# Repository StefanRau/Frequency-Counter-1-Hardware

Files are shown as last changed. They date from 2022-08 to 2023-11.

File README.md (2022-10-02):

# Frequency-Counter-1-hardware
This repository contains CAD data of Frequency Counter 1

Project repositories are:
- [Project](https://github.com/StefanRau/Frequency-Counter-1-Project)
- [Hardware](https://github.com/StefanRau/Frequency-Counter-1-Hardware)
- [Software](https://github.com/StefanRau/Frequency-Counter-1-Arduino)
- [PC terminal software](https://github.com/StefanRau/Frequency-Counter-1-Terminal)
## Main Board
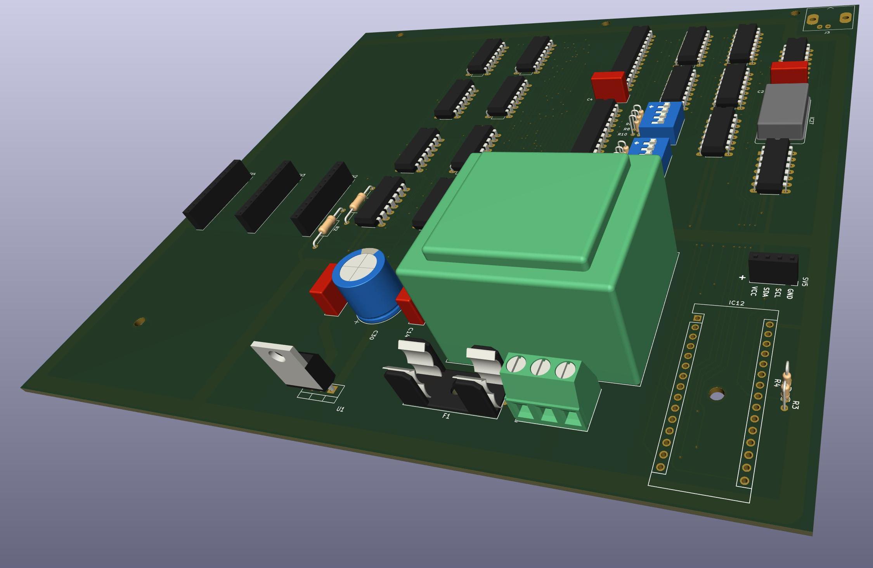
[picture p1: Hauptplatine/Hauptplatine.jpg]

## Front Plate
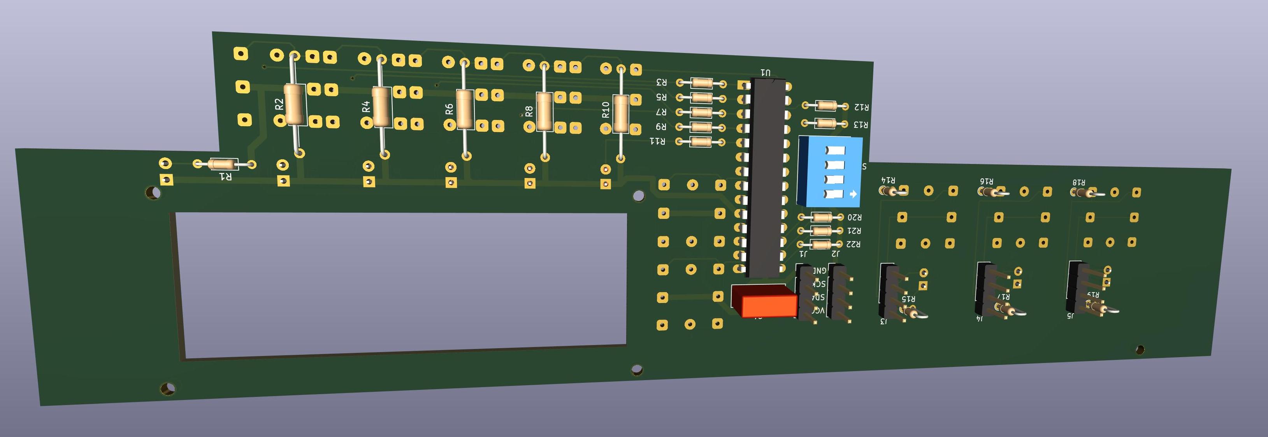
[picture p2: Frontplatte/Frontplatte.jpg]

## 100 MHz TTL CMOS
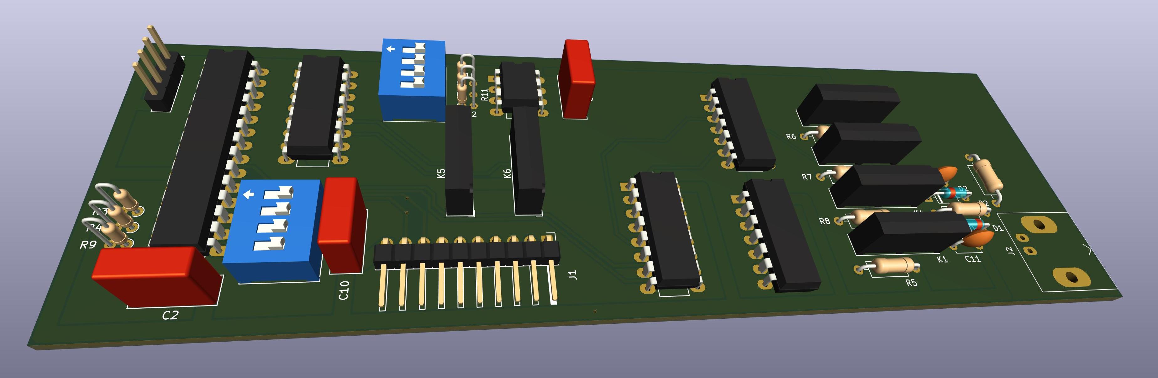
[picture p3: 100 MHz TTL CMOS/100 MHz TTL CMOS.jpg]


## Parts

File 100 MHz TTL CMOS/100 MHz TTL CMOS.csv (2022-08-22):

Source: | C:\Stefan\Backup\Projekte\Frequency Counter\V1.0\SchaltungKiCad\100 MHz TTL CMOS\100 MHz TTL CMOS.kicad_sch
Date: | 16.08.2022 20:28:54
Tool: | Eeschema (6.0.5)
Generator: | C:\Program Files\KiCad\6.0\bin\scripting\plugins/bom_csv_grouped_by_value_with_fp.py
Component Count: | 36
Ref | Qnty | Value | Cmp name | Footprint | Description | Vendor
C2, C4, C10, | 3 | 100nF | C-Device-100-MHz-TTL-CMOS-rescue | Capacitor_THT:C_Rect_L10.0mm_W4.0mm_P7.50mm_FKS3_FKP3
C11, C12, | 2 | 10pF | C-Device-100-MHz-TTL-CMOS-rescue | Capacitor_THT:C_Disc_D4.7mm_W2.5mm_P5.00mm
D1, D2, | 2 | BAT43 | BAT43-Diode-100-MHz-TTL-CMOS-rescue | Diode_THT:D_DO-35_SOD27_P7.62mm_Horizontal
IC1, | 1 | 74LS14 | 74HC14-74xx-100-MHz-TTL-CMOS-rescue | Package_DIP:DIP-14_W7.62mm_LongPads
IC2, | 1 | MCP23017_SO | MCP23017_SO-Interface_Expansion-100-MHz-TTL-CMOS-rescue | Package_DIP:DIP-28_W7.62mm_LongPads
IC3, | 1 | 74HC14 | 74HC14-74xx-100-MHz-TTL-CMOS-rescue | Package_DIP:DIP-14_W7.62mm_LongPads
IC4, | 1 | 24LC256 | 24LC256 | Package_DIP:DIP-8_W7.62mm_LongPads | I2C Serial EEPROM, 256Kb, DIP-8/SOIC-8/TSSOP-8/DFN-8
IC5, | 1 | 74HC151 | 74LS151-74xx-100-MHz-TTL-CMOS-rescue | Package_DIP:DIP-16_W7.62mm_LongPads
IC6, | 1 | ULN2003 | ULN2003-Transistor_Array-100-MHz-TTL-CMOS-rescue | Package_DIP:DIP-16_W7.62mm_LongPads
J1, | 1 | Conn_01x10_Male | Conn_01x10_Male-Connector-100-MHz-TTL-CMOS-rescue | Connector_PinHeader_2.54mm:PinHeader_1x10_P2.54mm_Horizontal
J2, | 1 | Conn_Coaxial | Conn_Coaxial-Connector-100-MHz-TTL-CMOS-rescue | Connector_Coaxial:BNC_Amphenol_B6252HB-NPP3G-50_Horizontal
J3, | 1 | Conn_01x04_Male | Conn_01x04_Male-Connector-100-MHz-TTL-CMOS-rescue | Connector_PinHeader_2.54mm:PinHeader_1x04_P2.54mm_Vertical
K1, K2, K3, K4, K5, K6, | 6 | UMS05-1A80-75D | UMS05-1A80-75D | Relay_THT:Relay_SPST_StandexMeder_MS_Form1AB | Standex Meder UMS reed relay, SPST, Closing Contact, with diode
R1, | 1 | 1M | R-Device-100-MHz-TTL-CMOS-rescue | Resistor_THT:R_Axial_DIN0207_L6.3mm_D2.5mm_P10.16mm_Horizontal
R2, | 1 | 330 | R-Device-100-MHz-TTL-CMOS-rescue | Resistor_THT:R_Axial_DIN0207_L6.3mm_D2.5mm_P10.16mm_Horizontal
R3, R4, R9, R10, R11, R12, | 6 | 4,7k | R-Device-100-MHz-TTL-CMOS-rescue | Resistor_THT:R_Axial_DIN0204_L3.6mm_D1.6mm_P1.90mm_Vertical
R5, R7, R8, | 3 | 4,7k | R-Device-100-MHz-TTL-CMOS-rescue | Resistor_THT:R_Axial_DIN0207_L6.3mm_D2.5mm_P10.16mm_Horizontal
R6, | 1 | 10k | R-Device-100-MHz-TTL-CMOS-rescue | Resistor_THT:R_Axial_DIN0207_L6.3mm_D2.5mm_P10.16mm_Horizontal
SW1, SW2, | 2 | SW_DIP_x04 | SW_DIP_x04-Switch-100-MHz-TTL-CMOS-rescue | Button_Switch_THT:SW_DIP_SPSTx04_Slide_9.78x12.34mm_W7.62mm_P2.54mm

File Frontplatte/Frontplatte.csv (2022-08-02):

Source: | C:\Users\d028312\OneDrive - SAP SE\Projekte\Frequency Counter\SchaltungKiCad\Frontplatte\Frontplatte.kicad_sch
Date: | 07.03.2022 16:20:37
Tool: | Eeschema (6.0.2)
Generator: | C:\Program Files\KiCad\6.0\bin\scripting\plugins/bom_csv_grouped_by_value.py
Component Count: | 49
Individual Components:
Item | Qty | Reference(s) | Value | LibPart | Footprint | Datasheet
 |  | C1 | 100nF | Frontplatte-rescue:C-Device-Frontplatte-rescue | Capacitor_THT:C_Rect_L10.0mm_W4.0mm_P7.50mm_FKS3_FKP3
 |  | D1 | LED | Frontplatte-rescue:LED-Device-Frontplatte-rescue | LED_THT:LED_D5.0mm
 |  | D2 | LED | Frontplatte-rescue:LED-Device-Frontplatte-rescue | LED_THT:LED_D5.0mm
 |  | D3 | LED | Frontplatte-rescue:LED-Device-Frontplatte-rescue | LED_THT:LED_D5.0mm
 |  | D4 | LED | Frontplatte-rescue:LED-Device-Frontplatte-rescue | LED_THT:LED_D5.0mm
 |  | D5 | LED | Frontplatte-rescue:LED-Device-Frontplatte-rescue | LED_THT:LED_D5.0mm
 |  | D6 | LED | Frontplatte-rescue:LED-Device-Frontplatte-rescue | LED_THT:LED_D5.0mm
 |  | D7 | LED | Frontplatte-rescue:LED-Device-Frontplatte-rescue | LED_THT:LED_D5.0mm
 |  | D8 | LED | Frontplatte-rescue:LED-Device-Frontplatte-rescue | LED_THT:LED_D5.0mm
 |  | D9 | LED | Frontplatte-rescue:LED-Device-Frontplatte-rescue | LED_THT:LED_D5.0mm
 |  | J1 | Conn_01x04_Male | Frontplatte-rescue:Conn_01x04_Male-Connector-Frontplatte-rescue | Connector_PinHeader_2.54mm:PinHeader_1x04_P2.54mm_Vertical
 |  | J2 | Conn_01x04_Male | Frontplatte-rescue:Conn_01x04_Male-Connector-Frontplatte-rescue | Connector_PinHeader_2.54mm:PinHeader_1x04_P2.54mm_Vertical
 |  | J3 | Conn_01x04_Male | Frontplatte-rescue:Conn_01x04_Male-Connector-Frontplatte-rescue | Connector_PinHeader_2.54mm:PinHeader_1x04_P2.54mm_Vertical
 |  | J4 | Conn_01x04_Male | Frontplatte-rescue:Conn_01x04_Male-Connector-Frontplatte-rescue | Connector_PinHeader_2.54mm:PinHeader_1x04_P2.54mm_Vertical
 |  | J5 | Conn_01x04_Male | Frontplatte-rescue:Conn_01x04_Male-Connector-Frontplatte-rescue | Connector_PinHeader_2.54mm:PinHeader_1x04_P2.54mm_Vertical
 |  | R1 | 220 | Frontplatte-rescue:R-Device-Frontplatte-rescue | Resistor_THT:R_Axial_DIN0204_L3.6mm_D1.6mm_P7.62mm_Horizontal
 |  | R2 | 4,7k | Frontplatte-rescue:R-Device-Frontplatte-rescue | Resistor_THT:R_Axial_DIN0207_L6.3mm_D2.5mm_P15.24mm_Horizontal
 |  | R3 | 220 | Frontplatte-rescue:R-Device-Frontplatte-rescue | Resistor_THT:R_Axial_DIN0204_L3.6mm_D1.6mm_P7.62mm_Horizontal
 |  | R4 | 4,7k | Frontplatte-rescue:R-Device-Frontplatte-rescue | Resistor_THT:R_Axial_DIN0207_L6.3mm_D2.5mm_P15.24mm_Horizontal
 |  | R5 | 220 | Frontplatte-rescue:R-Device-Frontplatte-rescue | Resistor_THT:R_Axial_DIN0204_L3.6mm_D1.6mm_P7.62mm_Horizontal
 |  | R6 | 4,7k | Frontplatte-rescue:R-Device-Frontplatte-rescue | Resistor_THT:R_Axial_DIN0207_L6.3mm_D2.5mm_P15.24mm_Horizontal
 |  | R7 | 220 | Frontplatte-rescue:R-Device-Frontplatte-rescue | Resistor_THT:R_Axial_DIN0204_L3.6mm_D1.6mm_P7.62mm_Horizontal
 |  | R8 | 4,7k | Frontplatte-rescue:R-Device-Frontplatte-rescue | Resistor_THT:R_Axial_DIN0207_L6.3mm_D2.5mm_P15.24mm_Horizontal
 |  | R9 | 220 | Frontplatte-rescue:R-Device-Frontplatte-rescue | Resistor_THT:R_Axial_DIN0204_L3.6mm_D1.6mm_P7.62mm_Horizontal
 |  | R10 | 4,7k | Frontplatte-rescue:R-Device-Frontplatte-rescue | Resistor_THT:R_Axial_DIN0207_L6.3mm_D2.5mm_P15.24mm_Horizontal
 |  | R11 | 220 | Frontplatte-rescue:R-Device-Frontplatte-rescue | Resistor_THT:R_Axial_DIN0204_L3.6mm_D1.6mm_P7.62mm_Horizontal
 |  | R12 | 4,7k | Frontplatte-rescue:R-Device-Frontplatte-rescue | Resistor_THT:R_Axial_DIN0204_L3.6mm_D1.6mm_P7.62mm_Horizontal
 |  | R13 | 4,7k | Frontplatte-rescue:R-Device-Frontplatte-rescue | Resistor_THT:R_Axial_DIN0204_L3.6mm_D1.6mm_P7.62mm_Horizontal
 |  | R14 | 4,7k | Frontplatte-rescue:R-Device-Frontplatte-rescue | Resistor_THT:R_Axial_DIN0204_L3.6mm_D1.6mm_P1.90mm_Vertical
 |  | R15 | 220 | Frontplatte-rescue:R-Device-Frontplatte-rescue | Resistor_THT:R_Axial_DIN0204_L3.6mm_D1.6mm_P1.90mm_Vertical
 |  | R16 | 4,7k | Frontplatte-rescue:R-Device-Frontplatte-rescue | Resistor_THT:R_Axial_DIN0204_L3.6mm_D1.6mm_P1.90mm_Vertical
 |  | R17 | 220 | Frontplatte-rescue:R-Device-Frontplatte-rescue | Resistor_THT:R_Axial_DIN0204_L3.6mm_D1.6mm_P1.90mm_Vertical
 |  | R18 | 4,7k | Frontplatte-rescue:R-Device-Frontplatte-rescue | Resistor_THT:R_Axial_DIN0204_L3.6mm_D1.6mm_P1.90mm_Vertical
 |  | R19 | 220 | Frontplatte-rescue:R-Device-Frontplatte-rescue | Resistor_THT:R_Axial_DIN0204_L3.6mm_D1.6mm_P1.90mm_Vertical
 |  | R20 | 4,7k | Frontplatte-rescue:R-Device-Frontplatte-rescue | Resistor_THT:R_Axial_DIN0204_L3.6mm_D1.6mm_P7.62mm_Horizontal
 |  | R21 | 4,7k | Frontplatte-rescue:R-Device-Frontplatte-rescue | Resistor_THT:R_Axial_DIN0204_L3.6mm_D1.6mm_P7.62mm_Horizontal
 |  | R22 | 4,7k | Frontplatte-rescue:R-Device-Frontplatte-rescue | Resistor_THT:R_Axial_DIN0204_L3.6mm_D1.6mm_P7.62mm_Horizontal
 |  | S1 | SCHADOW_Button | Frontplatte-rescue:SCHADOW_Button-Frequenzzähler-Frontplatte-rescue | Libs:SCHADOW_Button
 |  | S2 | SCHADOW_Button | Frontplatte-rescue:SCHADOW_Button-Frequenzzähler-Frontplatte-rescue | Libs:SCHADOW_Button
 |  | S3 | SCHADOW_Button | Frontplatte-rescue:SCHADOW_Button-Frequenzzähler-Frontplatte-rescue | Libs:SCHADOW_Button
 |  | S4 | SCHADOW_Button | Frontplatte-rescue:SCHADOW_Button-Frequenzzähler-Frontplatte-rescue | Libs:SCHADOW_Button
 |  | S5 | SCHADOW_Button | Frontplatte-rescue:SCHADOW_Button-Frequenzzähler-Frontplatte-rescue | Libs:SCHADOW_Button
 |  | S6 | SCHADOW_Button | Frontplatte-rescue:SCHADOW_Button-Frequenzzähler-Frontplatte-rescue | Libs:SCHADOW_Button
 |  | S7 | SCHADOW_Button | Frontplatte-rescue:SCHADOW_Button-Frequenzzähler-Frontplatte-rescue | Libs:SCHADOW_Button
 |  | S8 | SCHADOW_Button | Frontplatte-rescue:SCHADOW_Button-Frequenzzähler-Frontplatte-rescue | Libs:SCHADOW_Button
 |  | S9 | SCHADOW_Button | Frontplatte-rescue:SCHADOW_Button-Frequenzzähler-Frontplatte-rescue | Libs:SCHADOW_Button
 |  | S10 | SCHADOW_Button | Frontplatte-rescue:SCHADOW_Button-Frequenzzähler-Frontplatte-rescue | Libs:SCHADOW_Button
 |  | SW1 | SW_DIP_x04 | Frontplatte-rescue:SW_DIP_x04-Switch-Frontplatte-rescue | Button_Switch_THT:SW_DIP_SPSTx04_Slide_9.78x12.34mm_W7.62mm_P2.54mm
 |  | U1 | MCP23017_SP | Frontplatte-rescue:MCP23017_SP-Interface_Expansion-Frontplatte-rescue | Package_DIP:DIP-28_W7.62mm | http://ww1.microchip.com/downloads/en/DeviceDoc/20001952C.pdf
Collated Components:
Item | Qty | Reference(s) | Value | LibPart | Footprint | Datasheet
1 | 1 | C1 | 100nF | Frontplatte-rescue:C-Device-Frontplatte-rescue | Capacitor_THT:C_Rect_L10.0mm_W4.0mm_P7.50mm_FKS3_FKP3
2 | 9 | D1, D2, D3, D4, D5, D6, D7, D8, D9 | LED | Frontplatte-rescue:LED-Device-Frontplatte-rescue | LED_THT:LED_D5.0mm
3 | 5 | J1, J2, J3, J4, J5 | Conn_01x04_Male | Frontplatte-rescue:Conn_01x04_Male-Connector-Frontplatte-rescue | Connector_PinHeader_2.54mm:PinHeader_1x04_P2.54mm_Vertical
4 | 6 | R1, R3, R5, R7, R9, R11 | 220 | Frontplatte-rescue:R-Device-Frontplatte-rescue | Resistor_THT:R_Axial_DIN0204_L3.6mm_D1.6mm_P7.62mm_Horizontal
5 | 5 | R2, R4, R6, R8, R10 | 4,7k | Frontplatte-rescue:R-Device-Frontplatte-rescue | Resistor_THT:R_Axial_DIN0207_L6.3mm_D2.5mm_P15.24mm_Horizontal
6 | 5 | R12, R13, R20, R21, R22 | 4,7k | Frontplatte-rescue:R-Device-Frontplatte-rescue | Resistor_THT:R_Axial_DIN0204_L3.6mm_D1.6mm_P7.62mm_Horizontal
7 | 3 | R14, R16, R18 | 4,7k | Frontplatte-rescue:R-Device-Frontplatte-rescue | Resistor_THT:R_Axial_DIN0204_L3.6mm_D1.6mm_P1.90mm_Vertical
8 | 3 | R15, R17, R19 | 220 | Frontplatte-rescue:R-Device-Frontplatte-rescue | Resistor_THT:R_Axial_DIN0204_L3.6mm_D1.6mm_P1.90mm_Vertical
9 | 10 | S1, S2, S3, S4, S5, S6, S7, S8, S9, S10 | SCHADOW_Button | Frontplatte-rescue:SCHADOW_Button-Frequenzzähler-Frontplatte-rescue | Libs:SCHADOW_Button
10 | 1 | SW1 | SW_DIP_x04 | Frontplatte-rescue:SW_DIP_x04-Switch-Frontplatte-rescue | Button_Switch_THT:SW_DIP_SPSTx04_Slide_9.78x12.34mm_W7.62mm_P2.54mm
11 | 1 | U1 | MCP23017_SP | Frontplatte-rescue:MCP23017_SP-Interface_Expansion-Frontplatte-rescue | Package_DIP:DIP-28_W7.62mm | http://ww1.microchip.com/downloads/en/DeviceDoc/20001952C.pdf

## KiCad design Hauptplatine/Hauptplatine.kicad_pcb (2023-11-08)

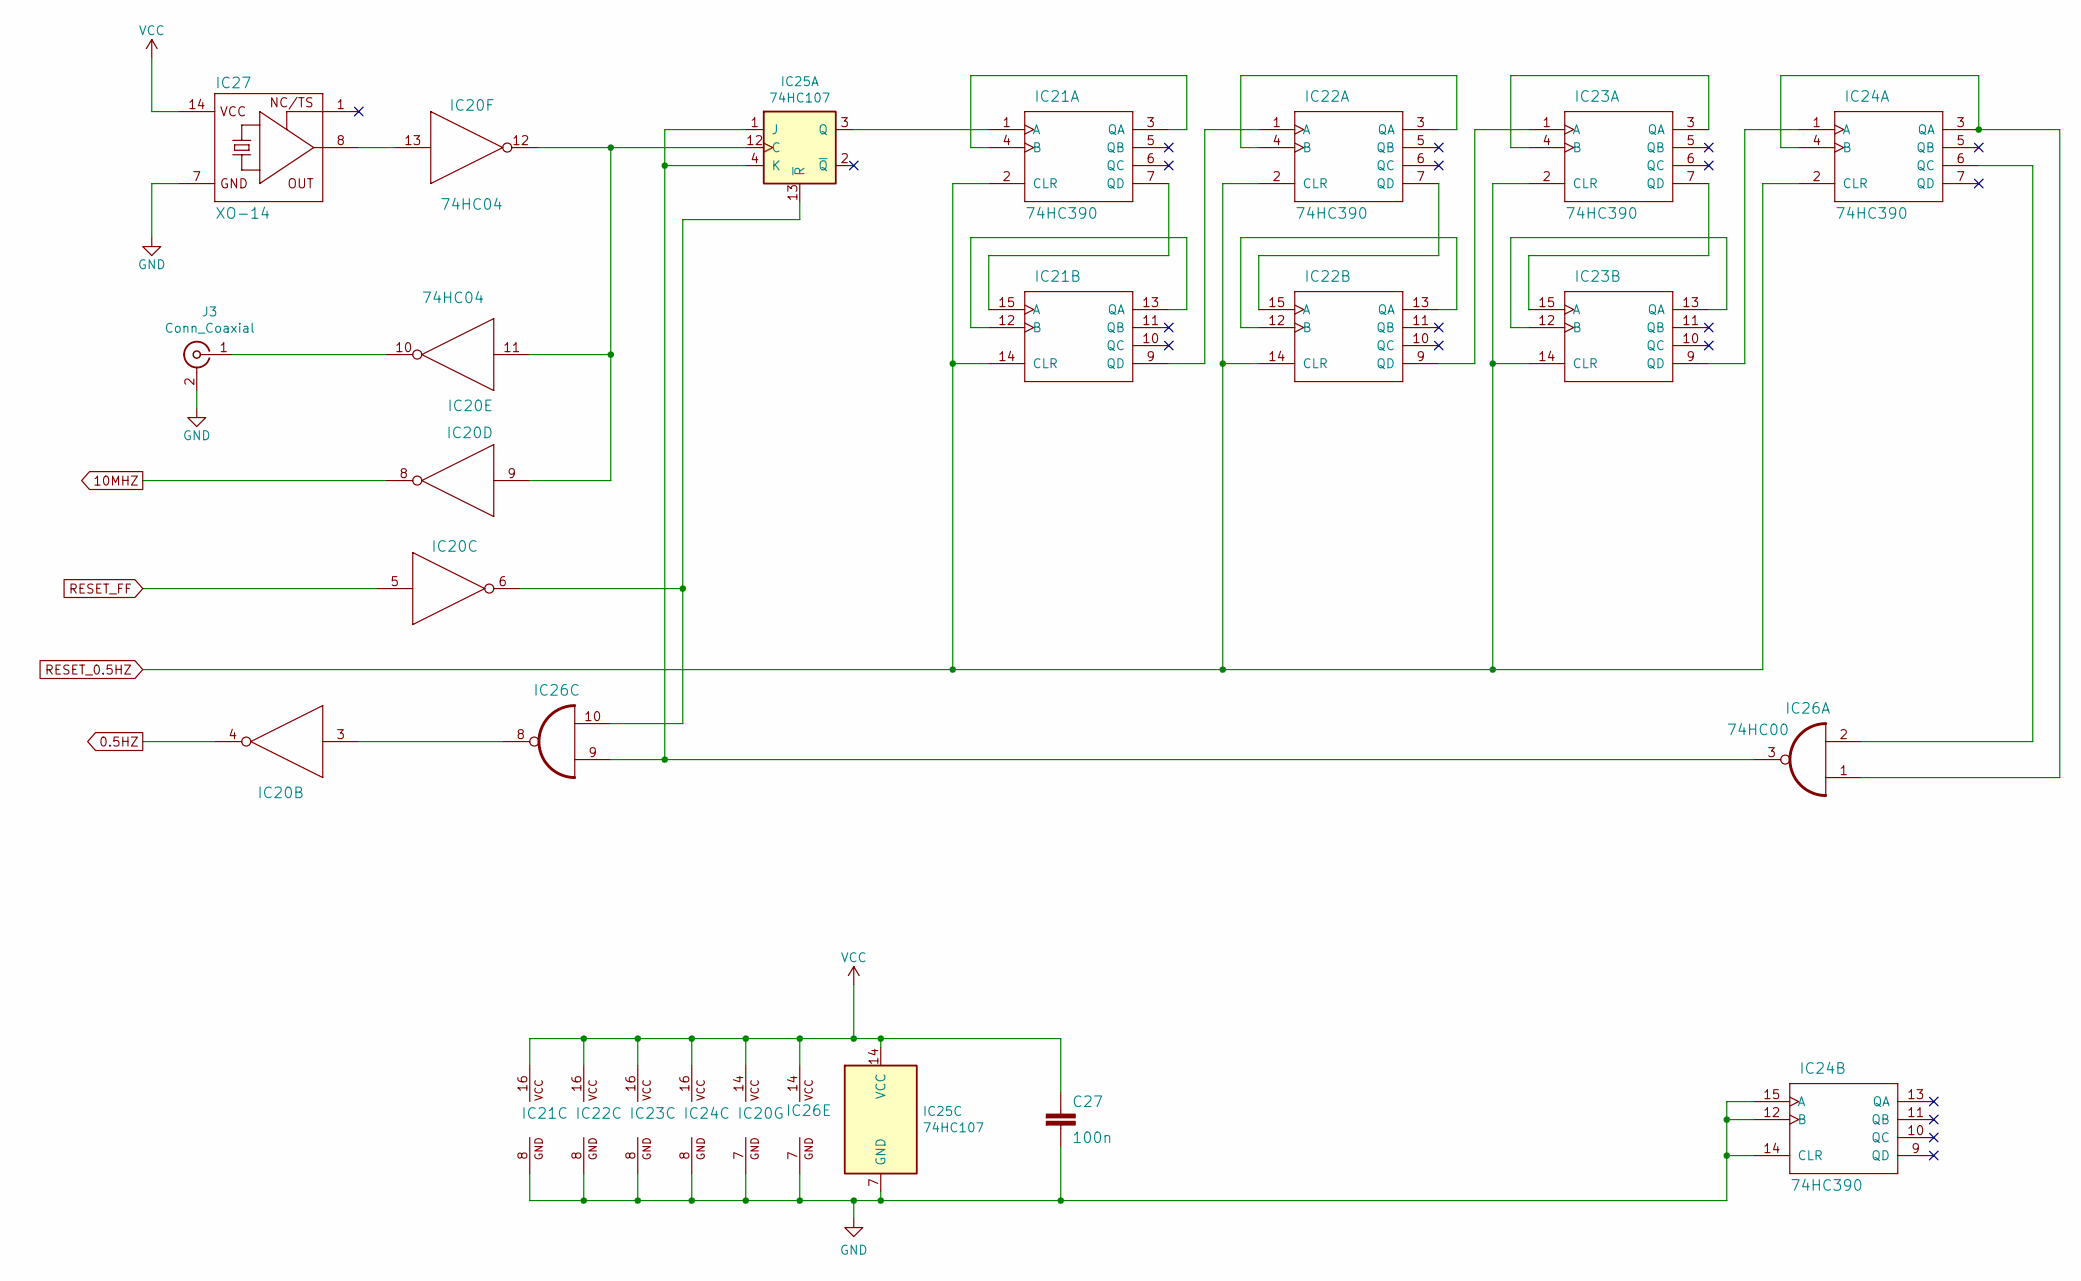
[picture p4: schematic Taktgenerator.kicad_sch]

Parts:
C27: 100n; C_Rect_L10.0mm_W4.0mm_P7.50mm_FKS3_FKP3
IC20: 74HC04; DIP-14_W7.62mm_LongPads
IC21, IC22, IC23, IC24: 74HC390; DIP-16_W7.62mm_LongPads
IC25: 74HC107; DIP-14_W7.62mm_LongPads
IC26: 74HC00; DIP-14_W7.62mm_LongPads
IC27: XO-14; Oscillator_DIP-14
J3: Conn_Coaxial; BNC_Amphenol_B6252HB-NPP3G-50_Horizontal

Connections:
0.5HZ: IC20.4 (O); also elsewhere on the board
10MHZ: IC20.8 (O); also elsewhere on the board
unnamed: IC20.3 (I), IC26.8 (O)
unnamed: IC20.6 (O), IC25.13 (~R), IC26.10 (I1)
unnamed: IC20.10 (O), J3.1 (In)
unnamed: IC20.9 (I), IC20.11 (I), IC20.12 (O), IC25.12 (C)
unnamed: IC20.13 (I), IC27.8 (OUT)
unnamed: IC21.1 (A), IC25.3 (Q)
unnamed: IC21.3 (QA), IC21.4 (B)
unnamed: IC21.9 (QD), IC22.1 (A)
unnamed: IC21.12 (B), IC21.13 (QA)
unnamed: IC21.7 (QD), IC21.15 (A)
unnamed: IC22.3 (QA), IC22.4 (B)
unnamed: IC22.9 (QD), IC23.1 (A)
unnamed: IC22.12 (B), IC22.13 (QA)
unnamed: IC22.7 (QD), IC22.15 (A)
unnamed: IC23.3 (QA), IC23.4 (B)
unnamed: IC23.9 (QD), IC24.1 (A)
unnamed: IC23.12 (B), IC23.13 (QA)
unnamed: IC23.7 (QD), IC23.15 (A)
unnamed: IC24.3 (QA), IC24.4 (B), IC26.1 (I0)
unnamed: IC24.6 (QC), IC26.2 (I1)
unnamed: IC25.1 (J), IC25.4 (K), IC26.3 (O), IC26.9 (I0)
RESET_0.5HZ: IC21.2 (CLR), IC21.14 (CLR), IC22.2 (CLR), IC22.14 (CLR), IC23.2 (CLR), IC23.14 (CLR), IC24.2 (CLR); also elsewhere on the board
RESET_FF: IC20.5 (I); also elsewhere on the board
VCC: C27.1, IC20.14 (VCC), IC21.16 (VCC), IC22.16 (VCC), IC23.16 (VCC), IC24.16 (VCC), IC25.14 (VCC), IC26.14 (VCC), IC27.14 (VCC); also elsewhere on the board

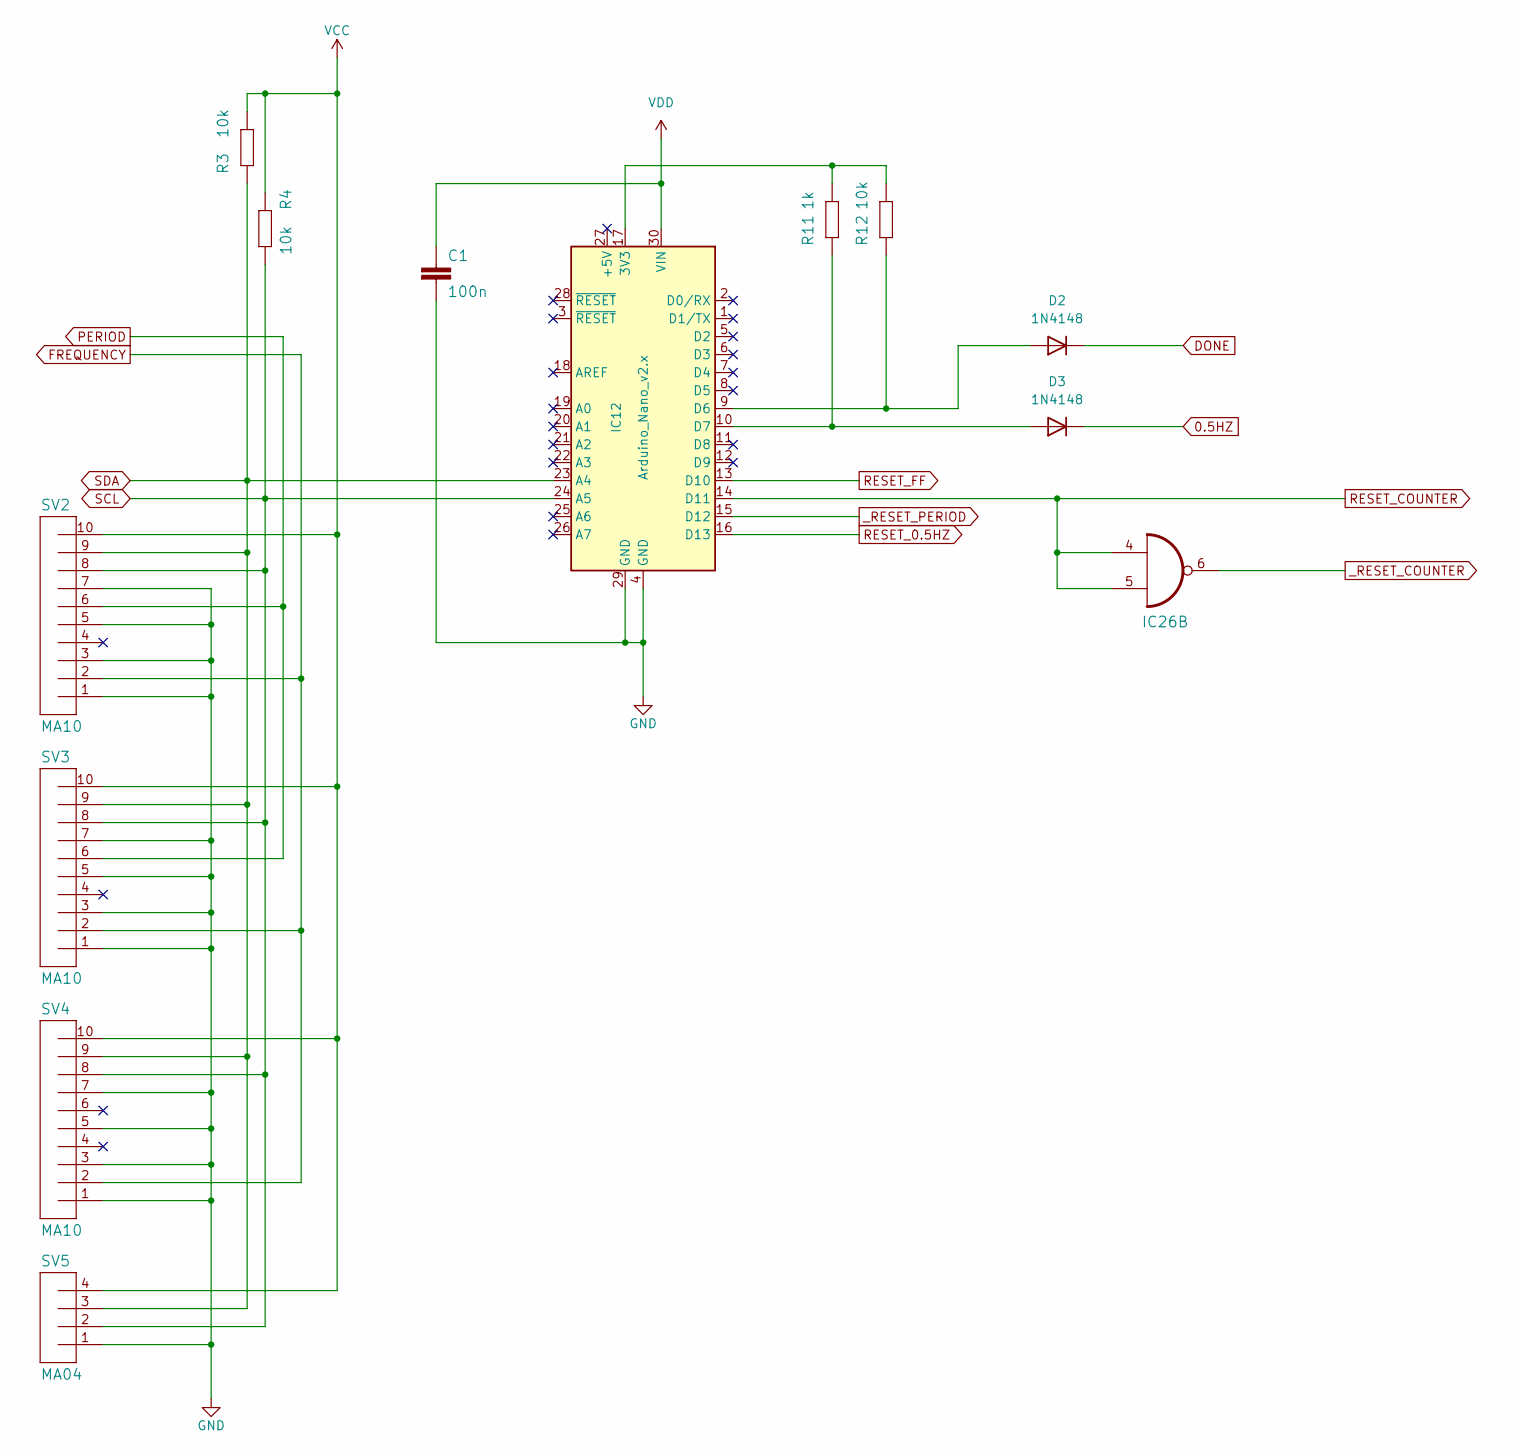
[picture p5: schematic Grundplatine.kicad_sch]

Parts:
C1: 100n; C_Rect_L10.0mm_W4.0mm_P7.50mm_FKS3_FKP3
D2, D3: 1N4148; D_DO-35_SOD27_P7.62mm_Horizontal
IC12: Arduino_Nano_v2.x; Arduino_Nano
IC26: 74HC00; DIP-14_W7.62mm_LongPads
R3, R4, R12: 10k; R_Axial_DIN0204_L3.6mm_D1.6mm_P1.90mm_Vertical
R11: 1k; R_Axial_DIN0204_L3.6mm_D1.6mm_P1.90mm_Vertical
SV2, SV3, SV4: MA10; PinSocket_1x10_P2.54mm_Vertical
SV5: MA04; PinSocket_1x04_P2.54mm_Vertical

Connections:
0.5HZ: D3.1 (K); also elsewhere on the board
DONE: D2.1 (K); also elsewhere on the board
FREQUENCY: SV2.2, SV3.2, SV4.2; also elsewhere on the board
unnamed: D2.2 (A), IC12.9 (D6), R12.1
unnamed: D3.2 (A), IC12.10 (D7), R11.1
unnamed: IC12.17 (3V3), R11.2, R12.2
PERIOD: SV2.6, SV3.6; also elsewhere on the board
RESET_0.5HZ: IC12.16 (D13); also elsewhere on the board
RESET_COUNTER: IC12.14 (D11), IC26.4 (I0), IC26.5 (I1); also elsewhere on the board
RESET_FF: IC12.13 (D10); also elsewhere on the board
SCL: IC12.24 (A5), R4.1, SV2.8, SV3.8, SV4.8, SV5.2; also elsewhere on the board
SDA: IC12.23 (A4), R3.1, SV2.9, SV3.9, SV4.9, SV5.3; also elsewhere on the board
VCC: R3.2, R4.2, SV2.10, SV3.10, SV4.10, SV5.4; also elsewhere on the board
VDD: C1.1, IC12.30 (VIN); also elsewhere on the board
_RESET_COUNTER: IC26.6 (O); also elsewhere on the board
_RESET_PERIOD: IC12.15 (D12); also elsewhere on the board

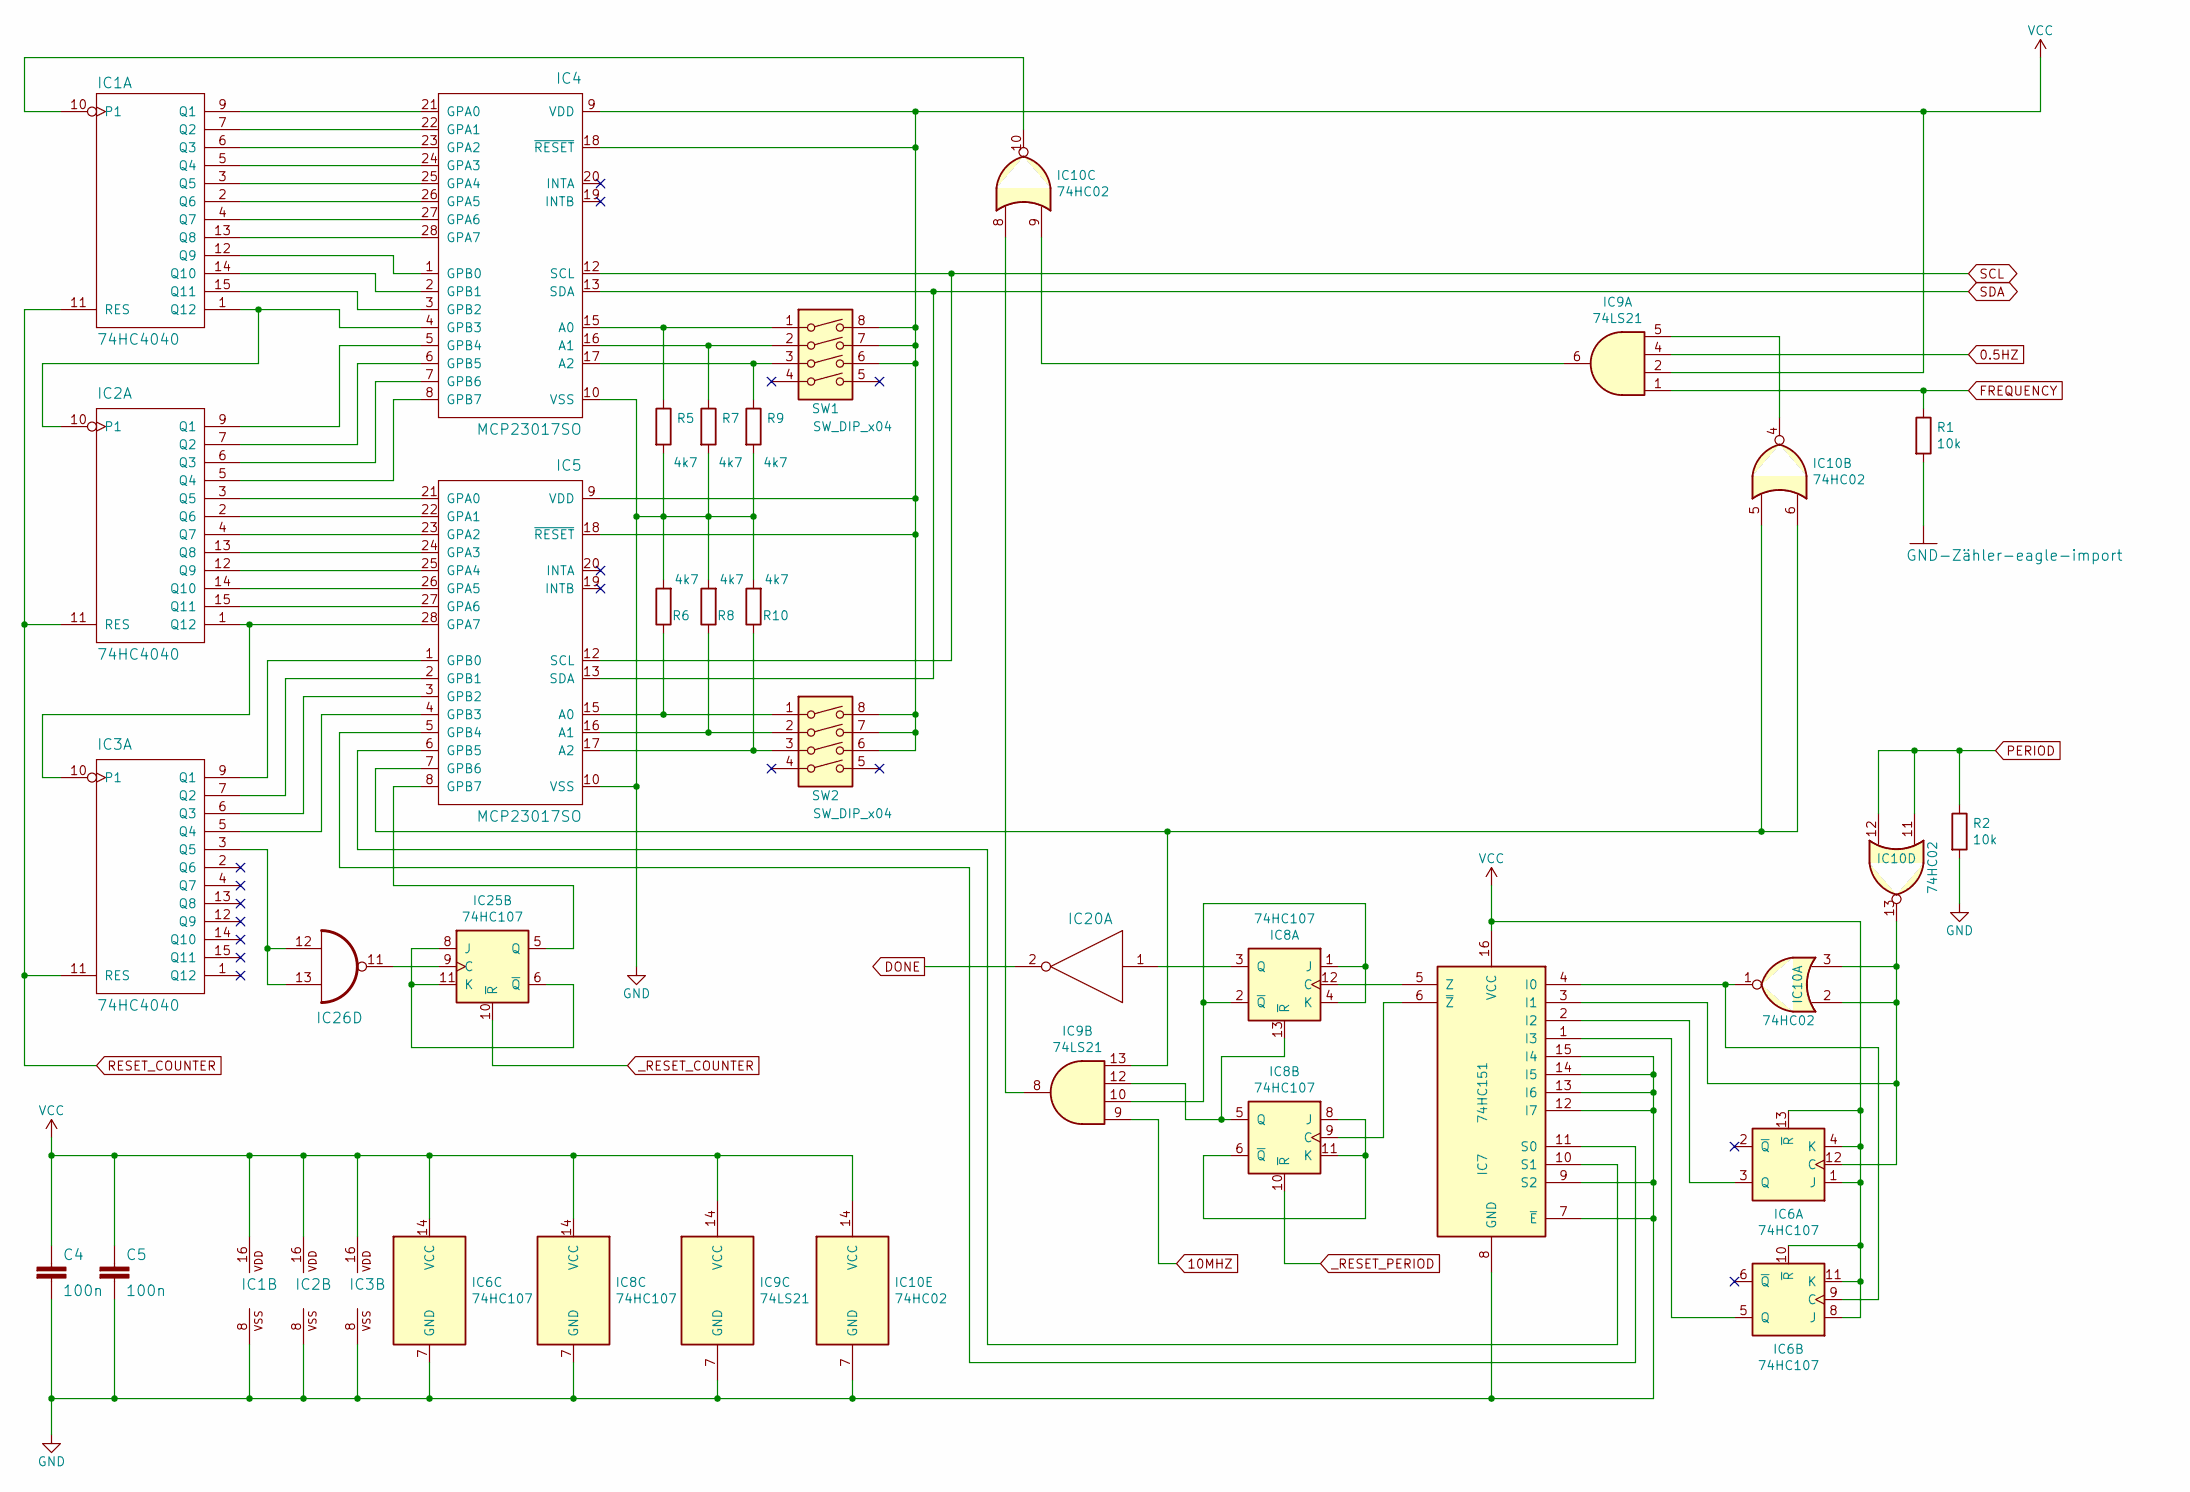
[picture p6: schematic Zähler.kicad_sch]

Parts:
C4, C5: 100n; C_Rect_L10.0mm_W4.0mm_P7.50mm_FKS3_FKP3
IC1, IC2, IC3: 74HC4040; DIP-16_W7.62mm_LongPads
IC4, IC5: MCP23017SO; DIP-28_W7.62mm_LongPads
IC6, IC8, IC25: 74HC107; DIP-14_W7.62mm_LongPads
IC7: 74HC151; DIP-16_W7.62mm_LongPads
IC9: 74LS21; DIP-14_W7.62mm_LongPads
IC10: 74HC02; DIP-14_W7.62mm_LongPads
IC20: 74HC04; DIP-14_W7.62mm_LongPads
IC26: 74HC00; DIP-14_W7.62mm_LongPads
R1, R2: 10k; R_Axial_DIN0207_L6.3mm_D2.5mm_P15.24mm_Horizontal
R5, R6, R7, R8, R9, R10: 4k7; R_Axial_DIN0204_L3.6mm_D1.6mm_P1.90mm_Vertical
SW1, SW2: SW_DIP_x04; SW_DIP_SPSTx04_Slide_9.78x12.34mm_W7.62mm_P2.54mm

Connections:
0.5HZ: IC9.4; also elsewhere on the board
10MHZ: IC9.9; also elsewhere on the board
DONE: IC20.2 (O); also elsewhere on the board
FREQUENCY: IC9.1, R1.1; also elsewhere on the board
unnamed: IC1.1 (Q12), IC2.10 (P1), IC4.4 (GPB3)
unnamed: IC1.2 (Q6), IC4.26 (GPA5)
unnamed: IC1.3 (Q5), IC4.25 (GPA4)
unnamed: IC1.4 (Q7), IC4.27 (GPA6)
unnamed: IC1.5 (Q4), IC4.24 (GPA3)
unnamed: IC1.6 (Q3), IC4.23 (GPA2)
unnamed: IC1.7 (Q2), IC4.22 (GPA1)
unnamed: IC1.9 (Q1), IC4.21 (GPA0)
unnamed: IC1.10 (P1), IC10.10
unnamed: IC1.12 (Q9), IC4.1 (GPB0)
unnamed: IC1.13 (Q8), IC4.28 (GPA7)
unnamed: IC1.14 (Q10), IC4.2 (GPB1)
unnamed: IC1.15 (Q11), IC4.3 (GPB2)
unnamed: IC2.1 (Q12), IC3.10 (P1), IC5.28 (GPA7)
unnamed: IC2.2 (Q6), IC5.22 (GPA1)
unnamed: IC2.3 (Q5), IC5.21 (GPA0)
unnamed: IC2.4 (Q7), IC5.23 (GPA2)
unnamed: IC2.5 (Q4), IC4.8 (GPB7)
unnamed: IC2.6 (Q3), IC4.7 (GPB6)
unnamed: IC2.7 (Q2), IC4.6 (GPB5)
unnamed: IC2.9 (Q1), IC4.5 (GPB4)
unnamed: IC2.12 (Q9), IC5.25 (GPA4)
unnamed: IC2.13 (Q8), IC5.24 (GPA3)
unnamed: IC2.14 (Q10), IC5.26 (GPA5)
unnamed: IC2.15 (Q11), IC5.27 (GPA6)
unnamed: IC3.5 (Q4), IC5.4 (GPB3)
unnamed: IC3.6 (Q3), IC5.3 (GPB2)
unnamed: IC3.7 (Q2), IC5.2 (GPB1)
unnamed: IC3.9 (Q1), IC5.1 (GPB0)
unnamed: IC4.15 (A0), R5.1, SW1.1
unnamed: IC4.16 (A1), R7.1, SW1.2
unnamed: IC4.17 (A2), R9.1, SW1.3
unnamed: IC5.5 (GPB4), IC7.11 (S0)
unnamed: IC5.6 (GPB5), IC7.10 (S1)
unnamed: IC5.15 (A0), R6.1, SW2.1
unnamed: IC5.16 (A1), R8.1, SW2.2
unnamed: IC5.17 (A2), R10.1, SW2.3
unnamed: IC6.3 (Q), IC7.2 (I2)
unnamed: IC6.5 (Q), IC7.1 (I3)
unnamed: IC7.5 (Z), IC8.12 (C)
unnamed: IC7.6 (~Z), IC8.9 (C)
unnamed: IC8.1 (J), IC8.2 (~Q), IC8.4 (K), IC9.10
unnamed: IC8.3 (Q), IC20.1 (I)
unnamed: IC8.6 (~Q), IC8.8 (J), IC8.11 (K)
unnamed: IC8.5 (Q), IC8.13 (~R), IC9.12
unnamed: IC6.9 (C), IC7.4 (I0), IC10.1
unnamed: IC9.5, IC10.4
unnamed: IC5.7 (GPB6), IC9.13, IC10.5, IC10.6
unnamed: IC9.8, IC10.8
unnamed: IC9.6, IC10.9
unnamed: IC6.12 (C), IC7.3 (I1), IC10.2, IC10.3, IC10.13
unnamed: IC5.8 (GPB7), IC25.5 (Q)
unnamed: IC25.9 (C), IC26.11 (O)
unnamed: IC25.6 (~Q), IC25.8 (J), IC25.11 (K)
unnamed: IC3.3 (Q5), IC26.12 (I0), IC26.13 (I1)
PERIOD: IC10.11, IC10.12, R2.1; also elsewhere on the board
RESET_COUNTER: IC1.11 (RES), IC2.11 (RES), IC3.11 (RES); also elsewhere on the board
SCL: IC4.12 (SCL), IC5.12 (SCL); also elsewhere on the board
SDA: IC4.13 (SDA), IC5.13 (SDA); also elsewhere on the board
VCC: C4.1, C5.1, IC1.16 (VDD), IC2.16 (VDD), IC3.16 (VDD), IC4.9 (VDD), IC4.18 (~RESET), IC5.9 (VDD), IC5.18 (~RESET), IC6.1 (J), IC6.4 (K), IC6.8 (J), IC6.10 (~R), IC6.11 (K), IC6.13 (~R), IC6.14 (VCC), IC7.16 (VCC), IC8.14 (VCC), IC9.2, IC9.14 (VCC), IC10.14 (VCC), SW1.6, SW1.7, SW1.8, SW2.6, SW2.7, SW2.8; also elsewhere on the board
_RESET_COUNTER: IC25.10 (~R); also elsewhere on the board
_RESET_PERIOD: IC8.10 (~R); also elsewhere on the board

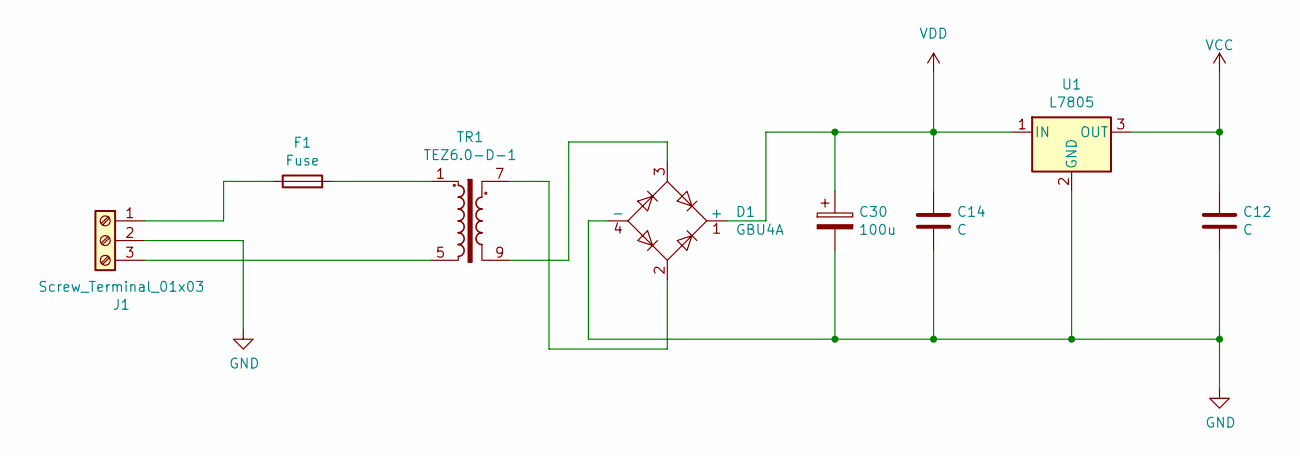
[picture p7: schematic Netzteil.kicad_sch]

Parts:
C12, C14: C; C_Rect_L10.0mm_W4.0mm_P7.50mm_FKS3_FKP3
C30: 100u; CP_Radial_D13.0mm_P5.00mm
D1: GBU4A; Diode_Bridge_Vishay_GBU
F1: Fuse; Fuseholder_Cylinder-5x20mm_Schurter_0031_8201_Horizontal_Op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
J1: Screw_Terminal_01x03; TerminalBlock_Phoenix_MKDS-1,5-3-5.08_1x03_P5.08mm_Horizont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
TR1: TEZ6.0-D-1; Transformer_Breve_TEZ-38x45
U1: L7805; TO-220-3_Vertical

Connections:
unnamed: D1.2, TR1.7
unnamed: D1.3, TR1.9
unnamed: F1.1, J1.1
unnamed: F1.2, TR1.1
unnamed: J1.3, TR1.5
VCC: C12.1, U1.3 (OUT); also elsewhere on the board
VDD: C14.1, C30.1, D1.1 (+), U1.1 (IN); also elsewhere on the board

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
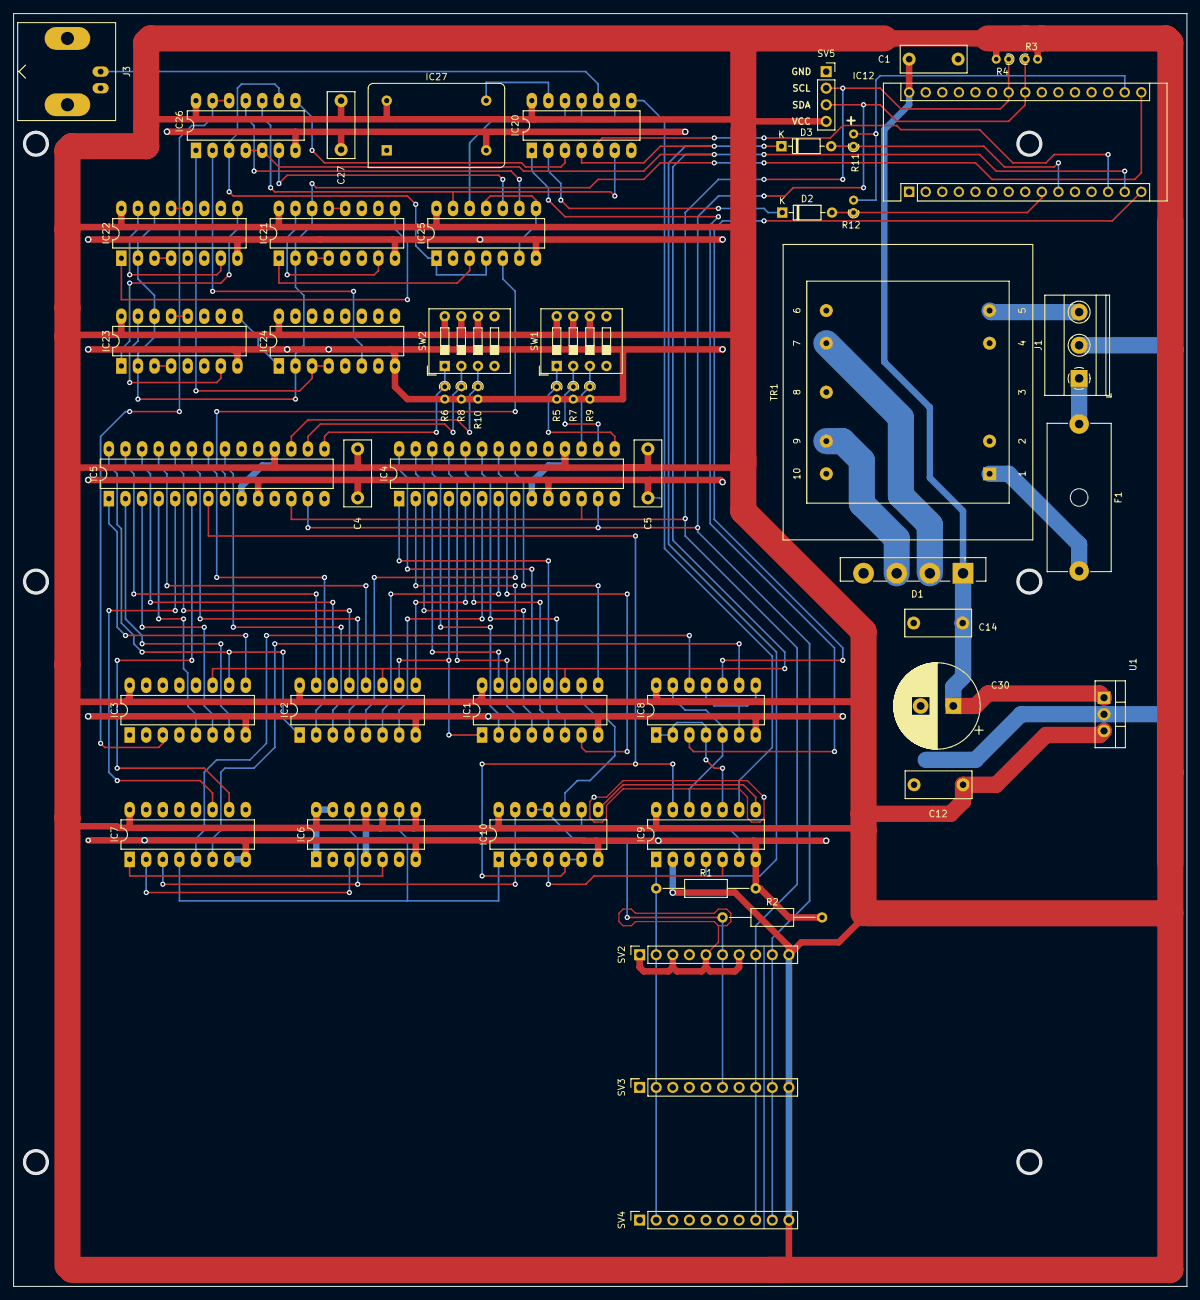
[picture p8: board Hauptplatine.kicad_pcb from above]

Board: 2 copper layers, 179.7 x 194.9 mm, 52 parts (0 on the bottom side), 99 nets.

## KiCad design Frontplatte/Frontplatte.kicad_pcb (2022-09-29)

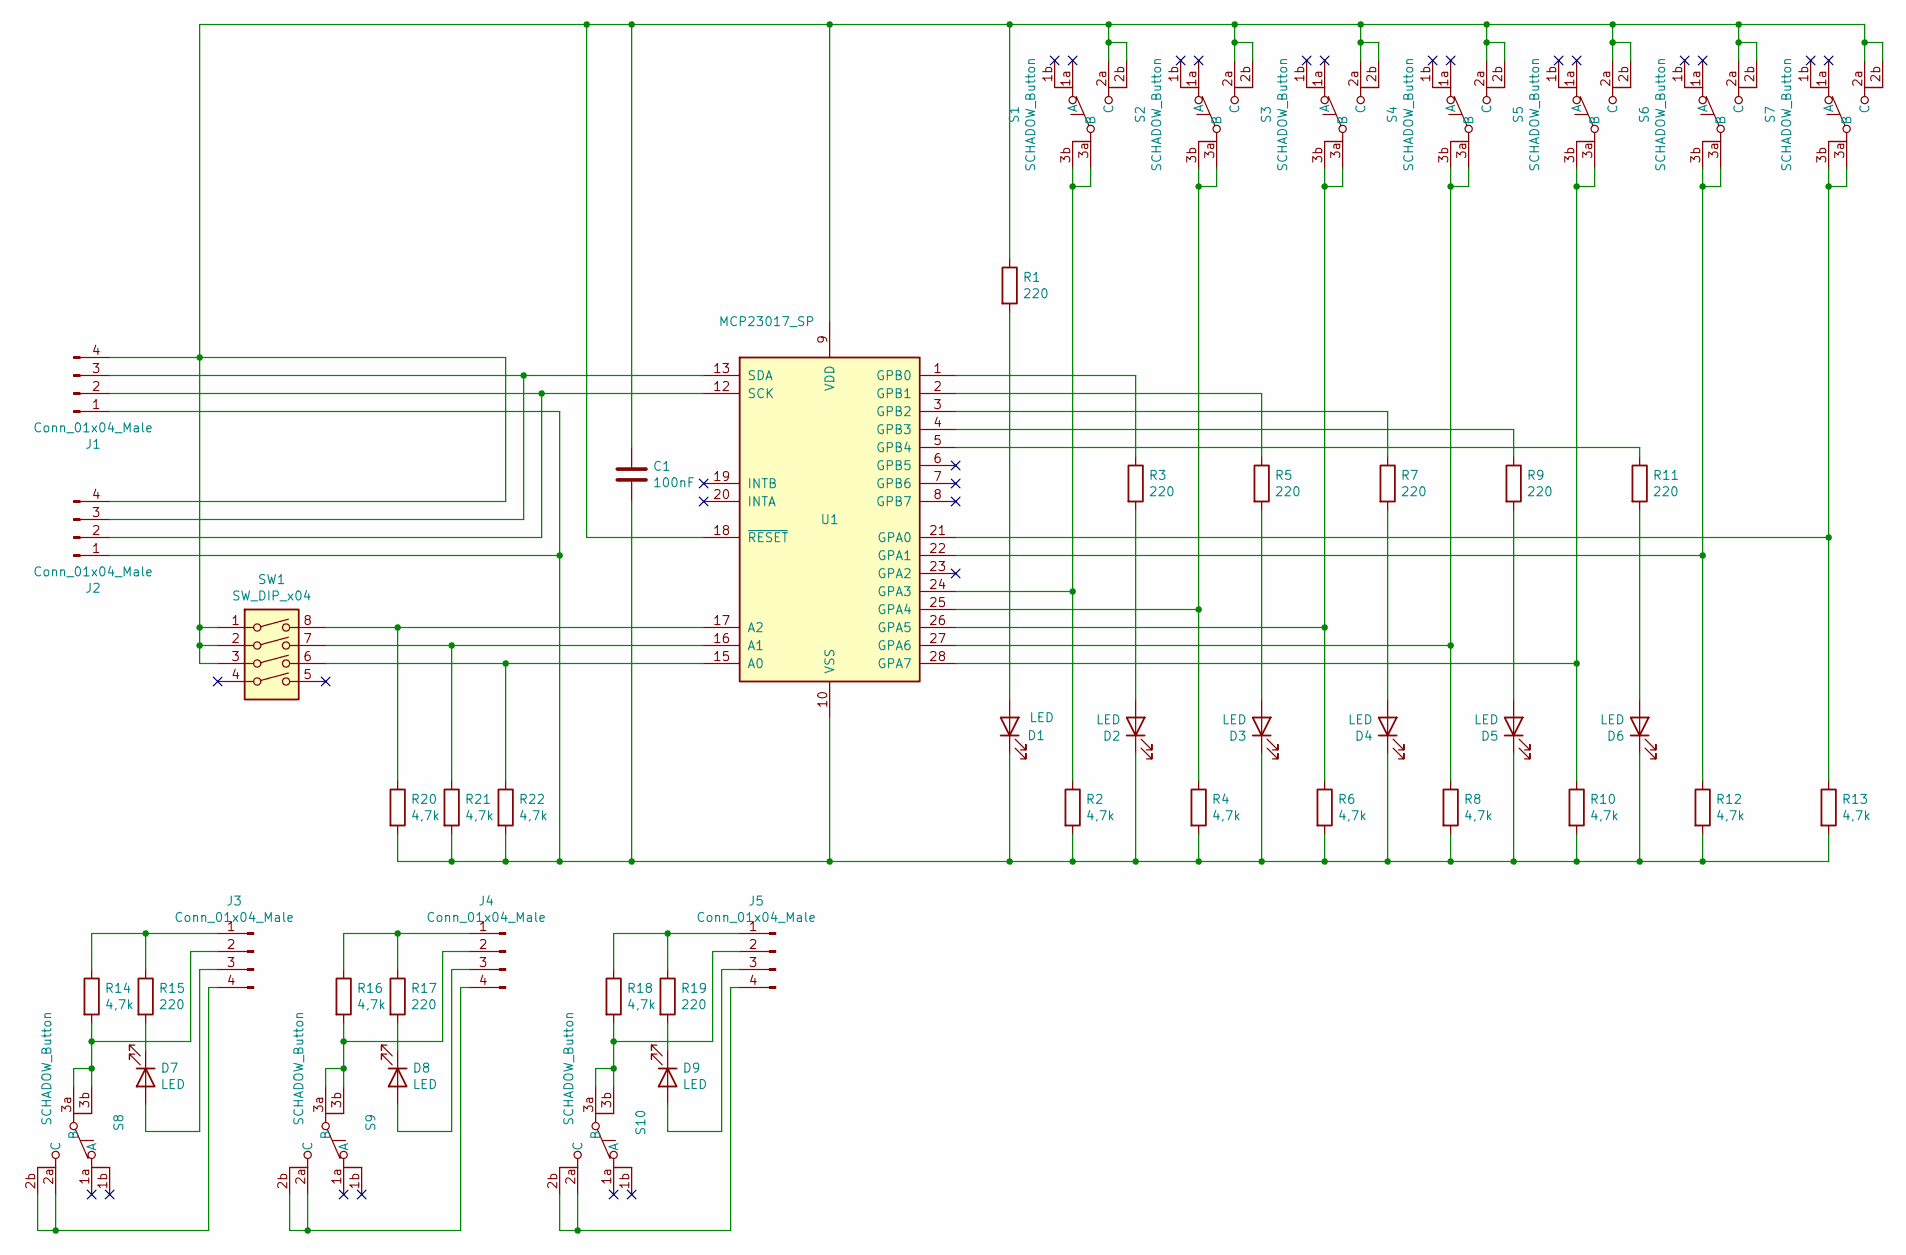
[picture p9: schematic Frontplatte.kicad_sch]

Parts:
C1: 100nF; C_Rect_L10.0mm_W4.0mm_P7.50mm_FKS3_FKP3
D1, D2, D3, D4, D5, D6, D7, D8, D9: LED; LED_D5.0mm
J1, J2, J3, J4, J5: Conn_01x04_Male; PinHeader_1x04_P2.54mm_Vertical
R1, R3, R5, R7, R9, R11: 220; R_Axial_DIN0204_L3.6mm_D1.6mm_P7.62mm_Horizontal
R2, R4, R6, R8, R10: 4,7k; R_Axial_DIN0207_L6.3mm_D2.5mm_P15.24mm_Horizontal
R12, R13, R20, R21, R22: 4,7k; R_Axial_DIN0204_L3.6mm_D1.6mm_P7.62mm_Horizontal
R14, R16, R18: 4,7k; R_Axial_DIN0204_L3.6mm_D1.6mm_P1.90mm_Vertical
R15, R17, R19: 220; R_Axial_DIN0204_L3.6mm_D1.6mm_P1.90mm_Vertical
S1, S2, S3, S4, S5, S6, S7, S8, S9, S10: SCHADOW_Button
SW1: SW_DIP_x04; SW_DIP_SPSTx04_Slide_9.78x12.34mm_W7.62mm_P2.54mm
U1: MCP23017_SP; DIP-28_W7.62mm_LongPads

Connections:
unnamed: C1.1, J1.4, J2.4, R1.1, S1.2a (C), S1.2b, S2.2a (C), S2.2b, S3.2a (C), S3.2b, S4.2a (C), S4.2b, S5.2a (C), S5.2b, S6.2a (C), S6.2b, S7.2a (C), S7.2b, SW1.1, SW1.2, SW1.3, U1.9 (VDD), U1.18 (~RESET)
unnamed: C1.2, D1.1 (K), D2.1 (K), D3.1 (K), D4.1 (K), D5.1 (K), D6.1 (K), J1.1, J2.1, R2.2, R4.2, R6.2, R8.2, R10.2, R12.2, R13.2, R20.2, R21.2, R22.2, U1.10 (VSS)
unnamed: D1.2 (A), R1.2
unnamed: D2.2 (A), R3.2
unnamed: D3.2 (A), R5.2
unnamed: D4.2 (A), R7.2
unnamed: D5.2 (A), R9.2
unnamed: D6.2 (A), R11.2
unnamed: D7.1 (K), R15.2
unnamed: D7.2 (A), J3.3
unnamed: D8.1 (K), R17.2
unnamed: D8.2 (A), J4.3
unnamed: D9.1 (K), R19.2
unnamed: D9.2 (A), J5.3
unnamed: J1.2, J2.2, U1.12 (SCK)
unnamed: J1.3, J2.3, U1.13 (SDA)
unnamed: J3.1, R14.1, R15.1
unnamed: J3.2, R14.2, S8.3a (B), S8.3b
unnamed: J3.4, S8.2a (C), S8.2b
unnamed: J4.1, R16.1, R17.1
unnamed: J4.2, R16.2, S9.3a (B), S9.3b
unnamed: J4.4, S9.2a (C), S9.2b
unnamed: J5.1, R18.1, R19.1
unnamed: J5.2, R18.2, S10.3a (B), S10.3b
unnamed: J5.4, S10.2a (C), S10.2b
unnamed: R2.1, S1.3a (B), S1.3b, U1.24 (GPA3)
unnamed: R3.1, U1.1 (GPB0)
unnamed: R4.1, S2.3a (B), S2.3b, U1.25 (GPA4)
unnamed: R5.1, U1.2 (GPB1)
unnamed: R6.1, S3.3a (B), S3.3b, U1.26 (GPA5)
unnamed: R7.1, U1.3 (GPB2)
unnamed: R8.1, S4.3a (B), S4.3b, U1.27 (GPA6)
unnamed: R9.1, U1.4 (GPB3)
unnamed: R10.1, S5.3a (B), S5.3b, U1.28 (GPA7)
unnamed: R11.1, U1.5 (GPB4)
unnamed: R12.1, S6.3a (B), S6.3b, U1.22 (GPA1)
unnamed: R13.1, S7.3a (B), S7.3b, U1.21 (GPA0)
unnamed: R20.1, SW1.8, U1.17 (A2)
unnamed: R21.1, SW1.7, U1.16 (A1)
unnamed: R22.1, SW1.6, U1.15 (A0)

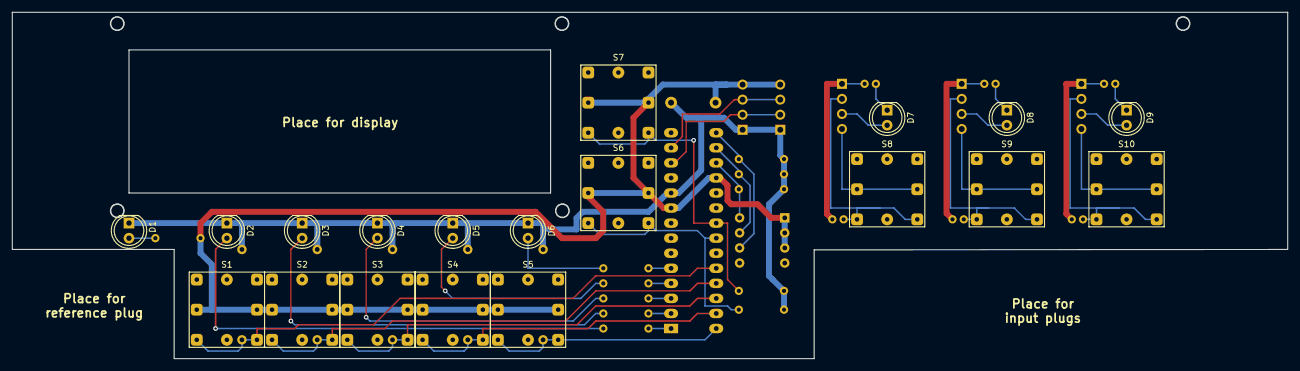
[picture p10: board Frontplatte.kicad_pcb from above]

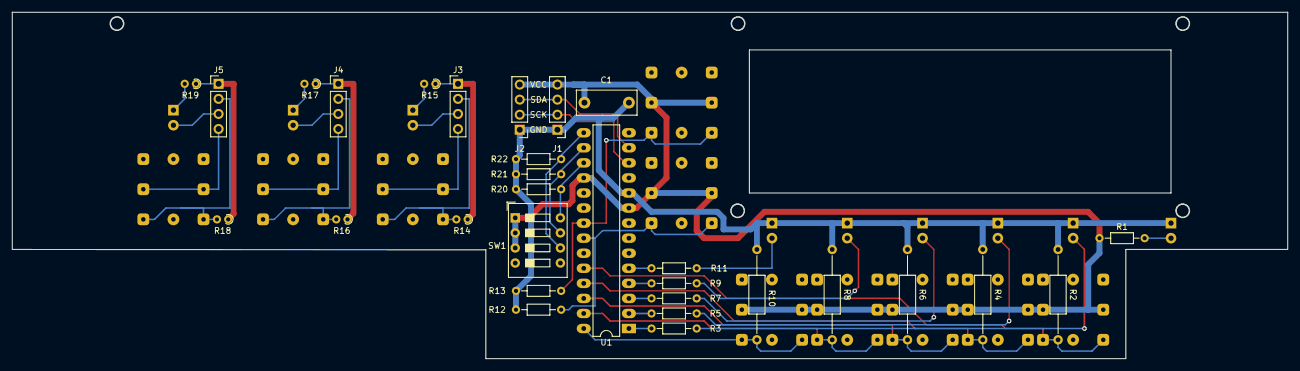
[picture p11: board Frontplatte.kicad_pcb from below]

Board: 2 copper layers, 215.1 x 58.4 mm, 49 parts (30 on the bottom side), 40 nets.

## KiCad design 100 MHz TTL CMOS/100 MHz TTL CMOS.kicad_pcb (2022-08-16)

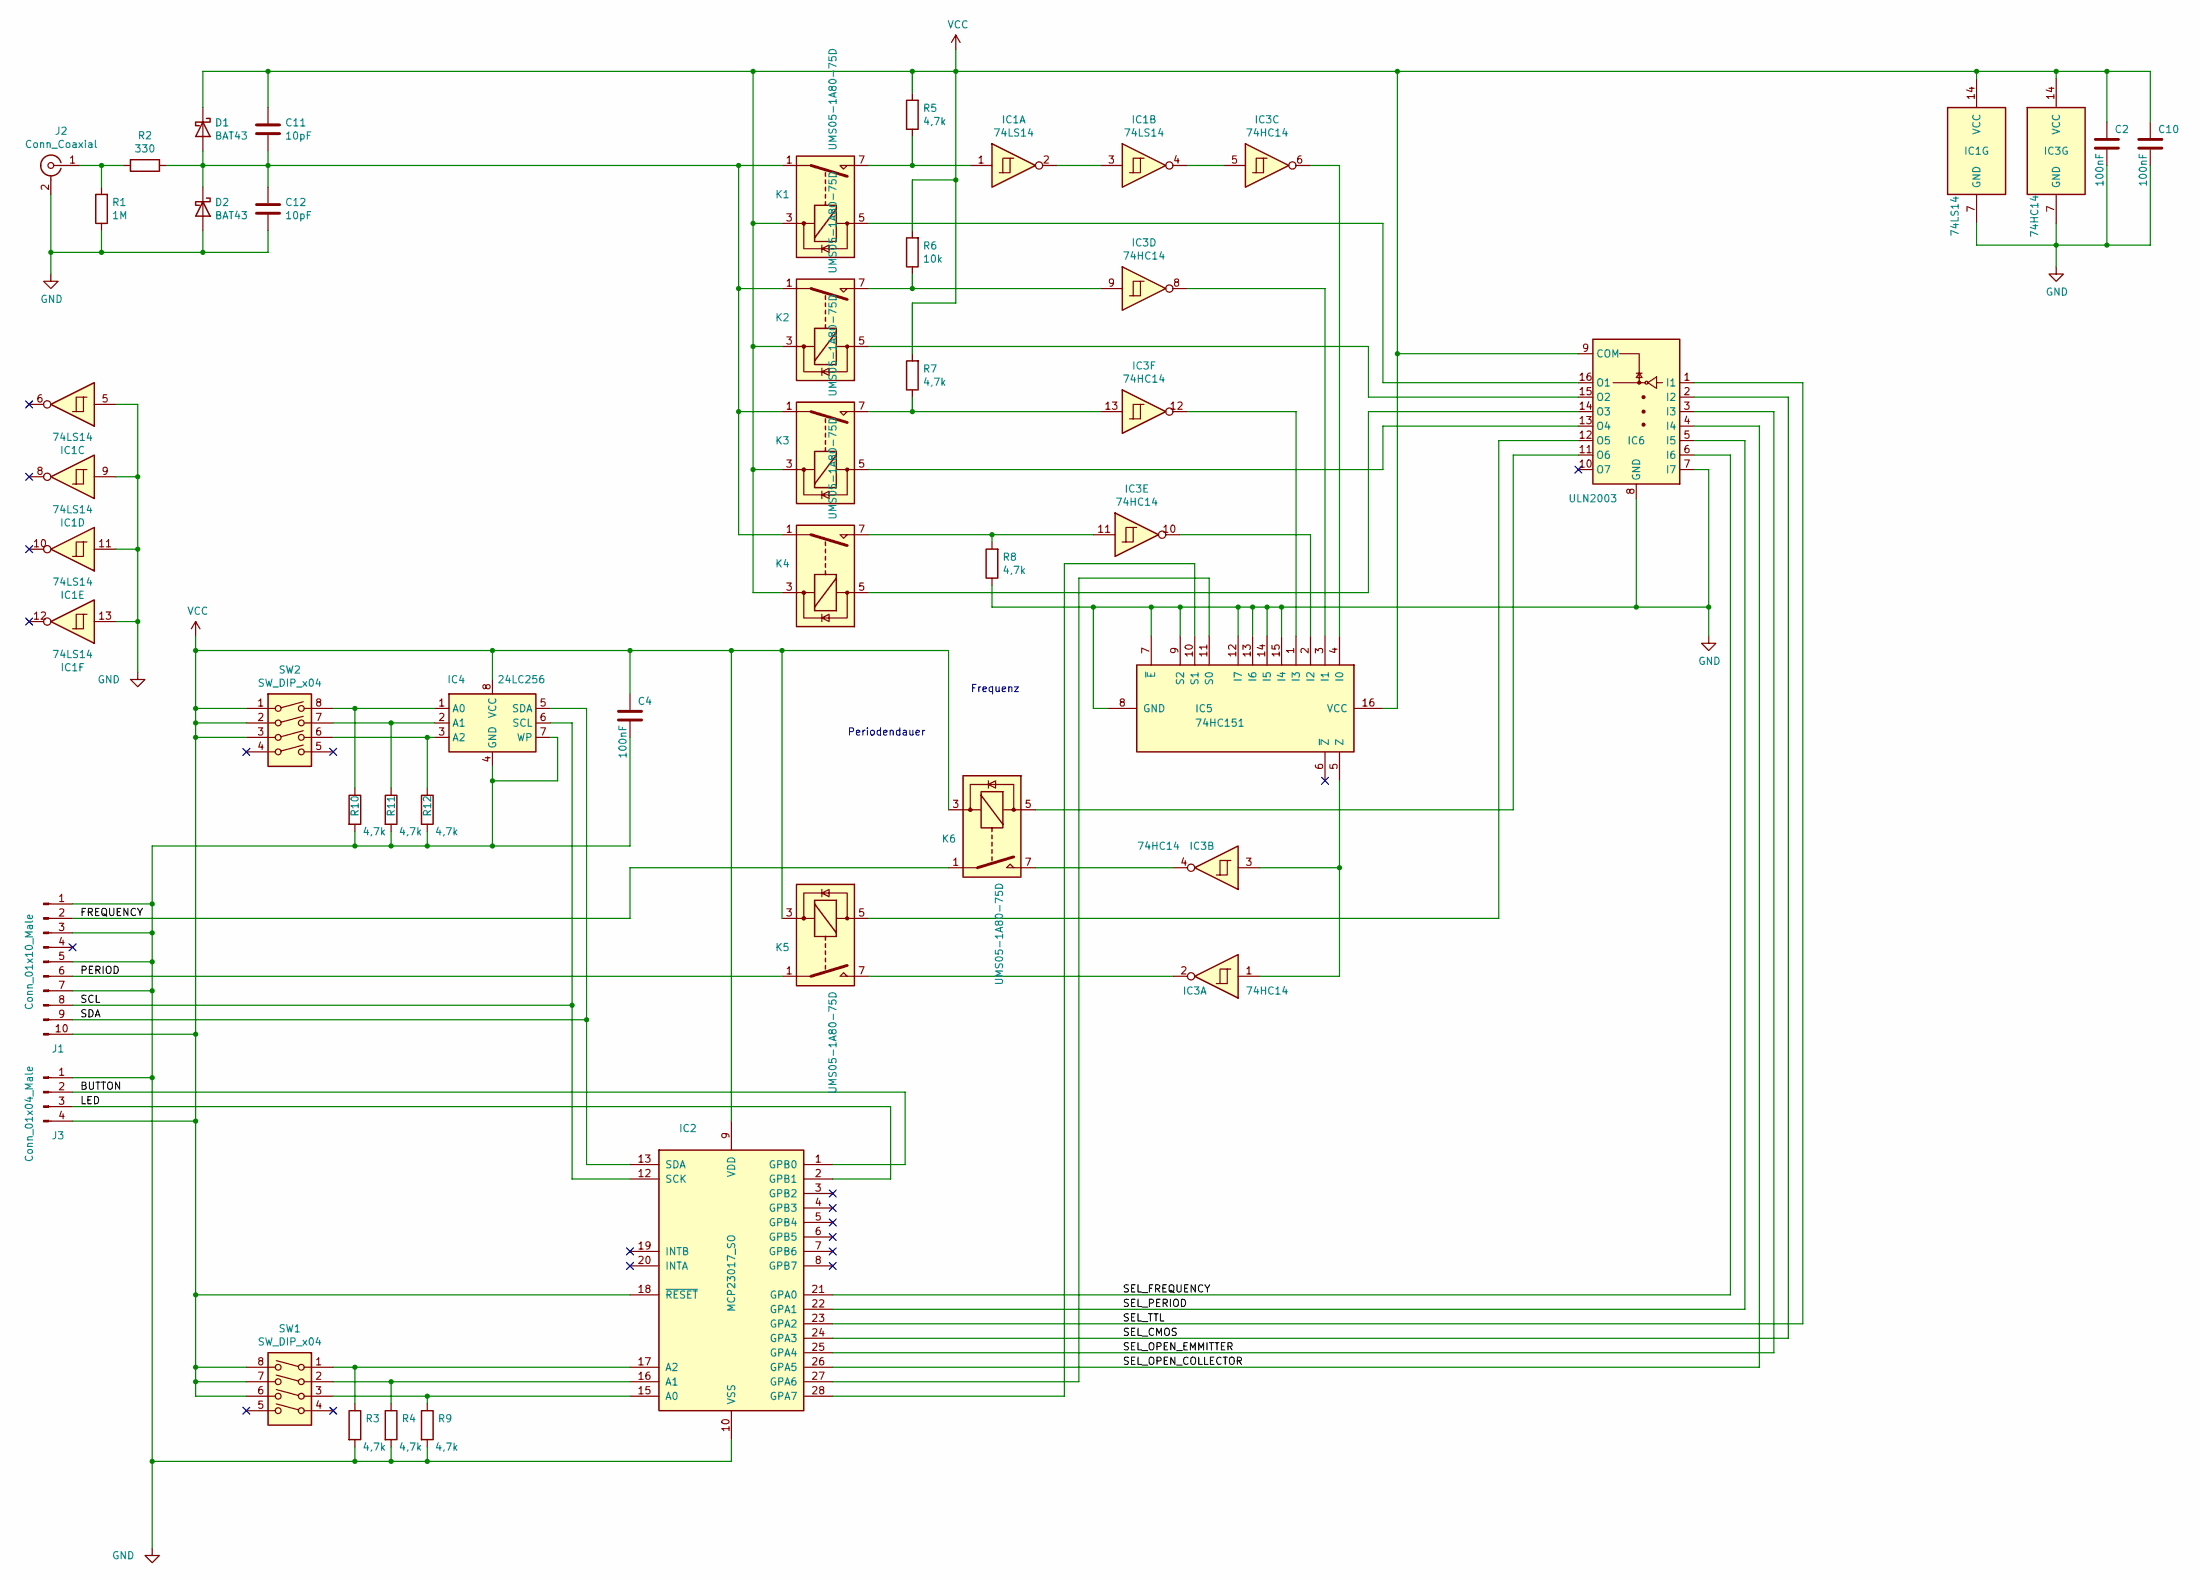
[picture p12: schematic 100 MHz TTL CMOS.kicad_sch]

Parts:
C2, C4, C10: 100nF; C_Rect_L10.0mm_W4.0mm_P7.50mm_FKS3_FKP3
C11, C12: 10pF; C_Disc_D4.7mm_W2.5mm_P5.00mm
D1, D2: BAT43; D_DO-35_SOD27_P7.62mm_Horizontal
IC1: 74LS14; DIP-14_W7.62mm_LongPads
IC2: MCP23017_SO; DIP-28_W7.62mm_LongPads
IC3: 74HC14; DIP-14_W7.62mm_LongPads
IC4: 24LC256; DIP-8_W7.62mm_LongPads
IC5: 74HC151; DIP-16_W7.62mm_LongPads
IC6: ULN2003; DIP-16_W7.62mm_LongPads
J1: Conn_01x10_Male; PinHeader_1x10_P2.54mm_Horizontal
J2: Conn_Coaxial; BNC_Amphenol_B6252HB-NPP3G-50_Horizontal
J3: Conn_01x04_Male; PinHeader_1x04_P2.54mm_Vertical
K1, K2, K3, K4, K5, K6: UMS05-1A80-75D; Relay_SPST_StandexMeder_MS_Form1AB
R1: 1M; R_Axial_DIN0207_L6.3mm_D2.5mm_P10.16mm_Horizontal
R2: 330; R_Axial_DIN0207_L6.3mm_D2.5mm_P10.16mm_Horizontal
R3, R4, R9, R10, R11, R12: 4,7k; R_Axial_DIN0204_L3.6mm_D1.6mm_P1.90mm_Vertical
R5, R7, R8: 4,7k; R_Axial_DIN0207_L6.3mm_D2.5mm_P10.16mm_Horizontal
R6: 10k; R_Axial_DIN0207_L6.3mm_D2.5mm_P10.16mm_Horizontal
SW1, SW2: SW_DIP_x04; SW_DIP_SPSTx04_Slide_9.78x12.34mm_W7.62mm_P2.54mm

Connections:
/BUTTON: IC2.1 (GPB0), J3.2
/FREQUENCY: J1.2, K6.1
/LED: IC2.2 (GPB1), J3.3
/PERIOD: J1.6, K5.1
/SCL: IC2.12 (SCK), IC4.6 (SCL), J1.8
/SDA: IC2.13 (SDA), IC4.5 (SDA), J1.9
/SEL_CMOS: IC2.24 (GPA3), IC6.2 (I2)
/SEL_FREQUENCY: IC2.21 (GPA0), IC6.6 (I6)
/SEL_OPEN_COLLECTOR: IC2.26 (GPA5), IC6.4 (I4)
/SEL_OPEN_EMMITTER: IC2.25 (GPA4), IC6.3 (I3)
/SEL_PERIOD: IC2.22 (GPA1), IC6.5 (I5)
/SEL_TTL: IC2.23 (GPA2), IC6.1 (I1)
GND: C2.2, C4.2, C10.2, C12.2, D2.2 (A), IC1.5, IC1.7 (GND), IC1.9, IC1.11, IC1.13, IC2.10 (VSS), IC3.7 (GND), IC4.4 (GND), IC4.7 (WP), IC5.7 (~E), IC5.8 (GND), IC5.9 (S2), IC5.12 (I7), IC5.13 (I6), IC5.14 (I5), IC5.15 (I4), IC6.7 (I7), IC6.8 (GND), J1.1, J1.3, J1.5, J1.7, J2.2 (Ext), J3.1, R1.1, R3.2, R4.2, R8.1, R9.2, R10.2, R11.2, R12.2
unnamed: C11.2, C12.1, D1.2 (A), D2.1 (K), K1.1, K2.1, K3.1, K4.1, R2.1
unnamed: IC1.1, K1.7, R5.1
unnamed: IC1.2, IC1.3
unnamed: IC1.4, IC3.5
unnamed: IC2.15 (A0), R9.1, SW1.3
unnamed: IC2.16 (A1), R4.1, SW1.2
unnamed: IC2.17 (A2), R3.1, SW1.1
unnamed: IC2.27 (GPA6), IC5.11 (S0)
unnamed: IC2.28 (GPA7), IC5.10 (S1)
unnamed: IC3.1, IC3.3, IC5.5 (Z)
unnamed: IC3.2, K5.7
unnamed: IC3.4, K6.7
unnamed: IC3.6, IC5.4 (I0)
unnamed: IC3.8, IC5.3 (I1)
unnamed: IC3.9, K2.7, R6.1
unnamed: IC3.10, IC5.2 (I2)
unnamed: IC3.11, K4.7, R8.2
unnamed: IC3.12, IC5.1 (I3)
unnamed: IC3.13, K3.7, R7.1
unnamed: IC4.1 (A0), R10.1, SW2.8
unnamed: IC4.2 (A1), R11.1, SW2.7
unnamed: IC4.3 (A2), R12.1, SW2.6
unnamed: IC6.11 (O6), K6.5
unnamed: IC6.12 (O5), K5.5
unnamed: IC6.13 (O4), K3.5
unnamed: IC6.14 (O3), K4.5
unnamed: IC6.15 (O2), K2.5
unnamed: IC6.16 (O1), K1.5
unnamed: J2.1 (In), R1.2, R2.2
VCC: C2.1, C4.1, C10.1, C11.1, D1.1 (K), IC1.14 (VCC), IC2.9 (VDD), IC2.18 (~RESET), IC3.14 (VCC), IC4.8 (VCC), IC5.16 (VCC), IC6.9 (COM), J1.10, J3.4, K1.3, K2.3, K3.3, K4.3, K5.3, K6.3, R5.2, R6.2, R7.2, SW1.6, SW1.7, SW1.8, SW2.1, SW2.2, SW2.3

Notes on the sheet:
Periodendauer
Frequenz

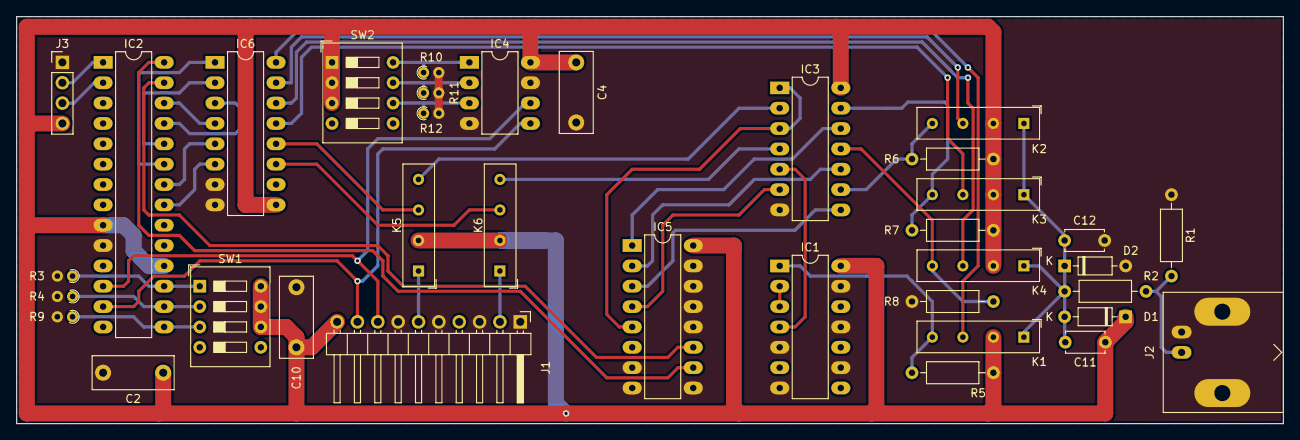
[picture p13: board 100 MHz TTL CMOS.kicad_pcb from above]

Board: 2 copper layers, 158.1 x 50.8 mm, 36 parts (0 on the bottom side), 43 nets.

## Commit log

2022-08-11 Short break in reset
    [Grundplatine.kicad_sch, Hauptplatine.kicad_pcb, Taktgenerator.kicad_sch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]
2022-08-11 Reset Logic updated
    [Hauptplatine.kicad_pcb]
2022-08-16 Update 100 MHz TTL CMOS.kicad_prl
2022-09-29 Inserted 3D models into Front Plate
    [Frontplatte.kicad_pcb, Frontplatte.kicad_sch]
2022-10-25 3,3 V compatible inputs
    [Grundplatine.kicad_sch, Netzteil.kicad_sch, Taktgenerator.kicad_sch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]
2023-11-08 Update
    Update
    [Grundplatine.kicad_sch, Hauptplatine.kicad_pcb, Hauptplatine.kicad_sch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]
